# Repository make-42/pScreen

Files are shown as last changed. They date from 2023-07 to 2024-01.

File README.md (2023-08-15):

# pScreen
A small screen for displaying computer information.

## Demo video
Demo video (https://youtu.be/9QAvDlJI2AM "Demo video")

## BOM
- Raspberry Pi Pico (5.00€)
- SSD1322 (256x64) (19.08€)
- PLA for the case (0.20€)
- Various M2 screws and nuts length (choose those that fit best for your build format) (0.40€)
- Wires (0.40€)

Total: 25.08€

## Building
### 3D Printed Parts
Print all files starting with `SSD1322_` in `CAD/STLs/`.

Rotate the pieces in your slicer accordingly and print with standard settings and no supports.

(note: These files are generated from the OpenSCAD files in `CAD/OpenSCAD/`. You can modify and create new presets in the `.json` files in that directory and generate the corresponding files using OpenSCAD. The variables are made to be copied between the files. This enables quickly adding support for new screens.).

### Wiring
Wire all the parts up according to this diagram (found in `CAD/Fritzing/`).
SSD 1322 wiring

### Software
#### Firmware
Building the firmware for the Raspberry Pi Pico is as easy as installing the dependencies (`cmake` and `gcc`), cd-ing into `Software/Firmware/` and running:
```sh
git submodule update --init --recursive
sh build.sh
```
The built `.uf2` firmware files are located in `Software/Firmware/build/`.

You just need to boot your Raspberry Pi Pico into BOOTSEL mode and drag and drop them into the mounted drive to upload the firmware.

#### Client
Building the client is as simple as installing `golang`, cd-ing into `Software/Companion App/` and running:
```sh
go mod tidy
go build
```

You can then run the client with:
```sh
./pscreen
```

You can then select the connected device by pressing `b` and start broadcasting to it with `s`.

Adding and removing modules is pretty self explanatory (use `a` and `r`).

Some parameters for the client such as module tweaks, client language, resolution, speed and timeouts can be changed in `Software/Companion App/config/config.go`.

Changing these parameters requires recompiling the software.

## Afterword
I have tried making the whole project as modular and tweakable as possible. You can add new modules and new support for new screens pretty easily. If you do, don't forget to create a pull request.

If you have any questions, you can open an issue. I'd be happy to help!

Most importantly, have fun!

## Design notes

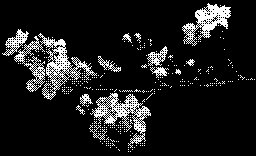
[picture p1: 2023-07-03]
Mockups/assets/bg.png

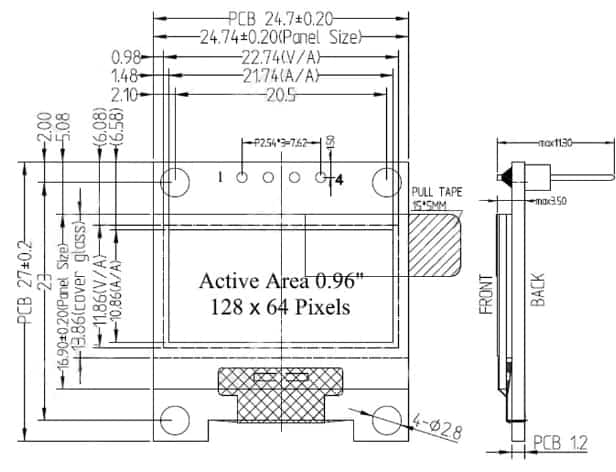
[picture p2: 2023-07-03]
CAD/Ref/oled-128x64-dimensions.jpg

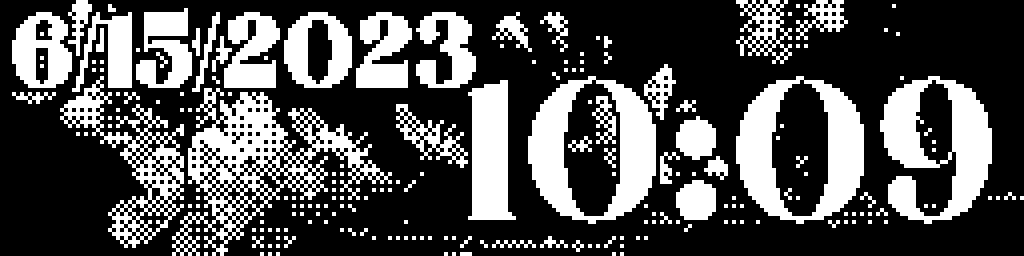
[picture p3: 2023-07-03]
Mockups/mockup-2-4x.png

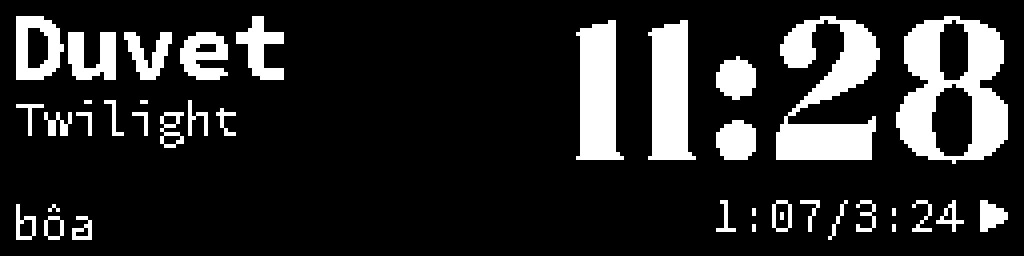
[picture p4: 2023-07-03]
Mockups/media-mockup-1-4x.png

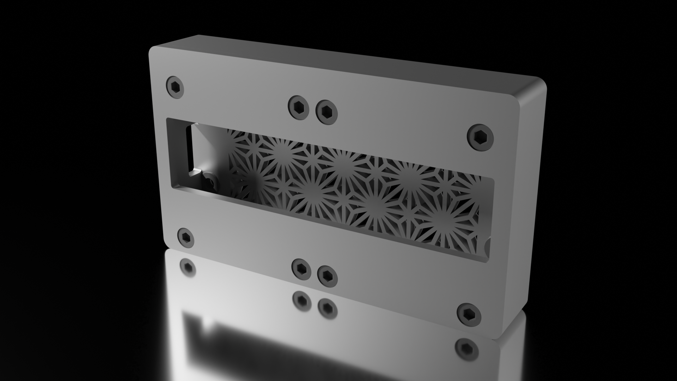
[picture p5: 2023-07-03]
CAD/Blender/cam1.png

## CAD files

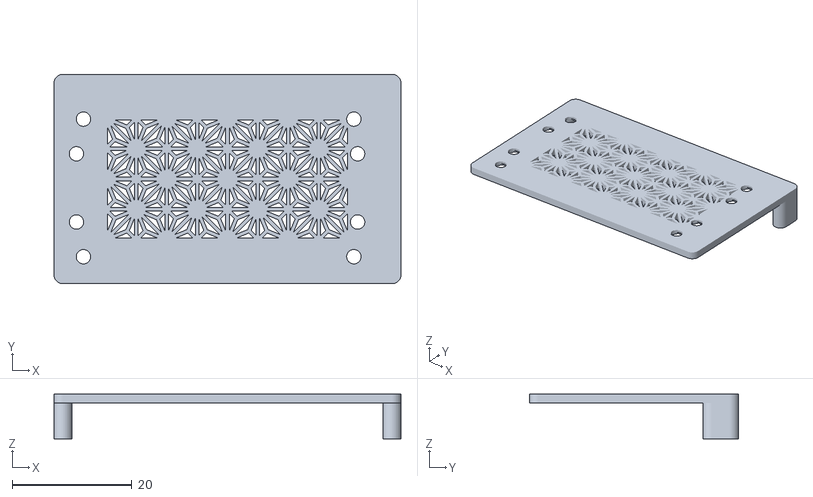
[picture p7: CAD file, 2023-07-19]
CAD/STLs/SSD1306_bottom.stl
58.0 x 35.0 x 7.50

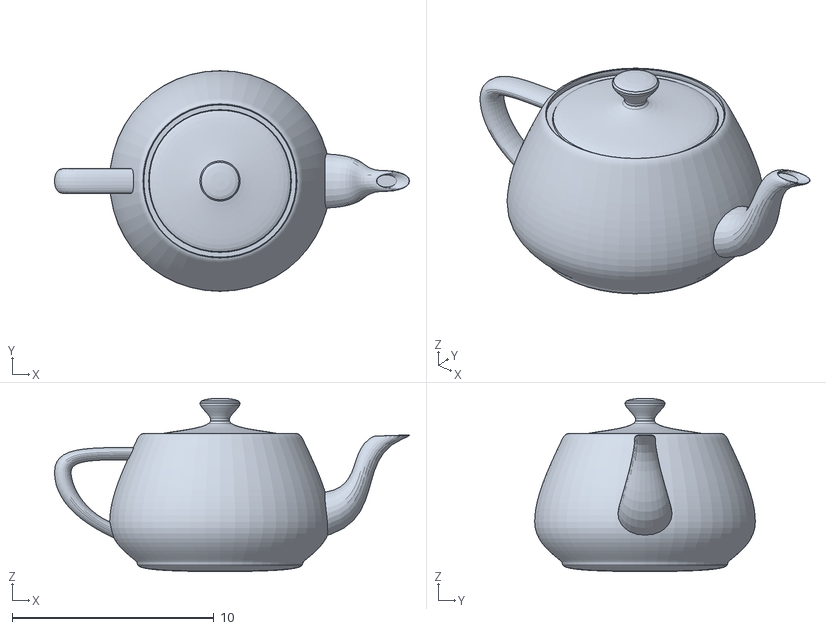
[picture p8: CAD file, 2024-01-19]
Software/Companion App/bridge/renderer/assets/3dmodels/teapot.stl
17.6 x 10.9 x 8.57

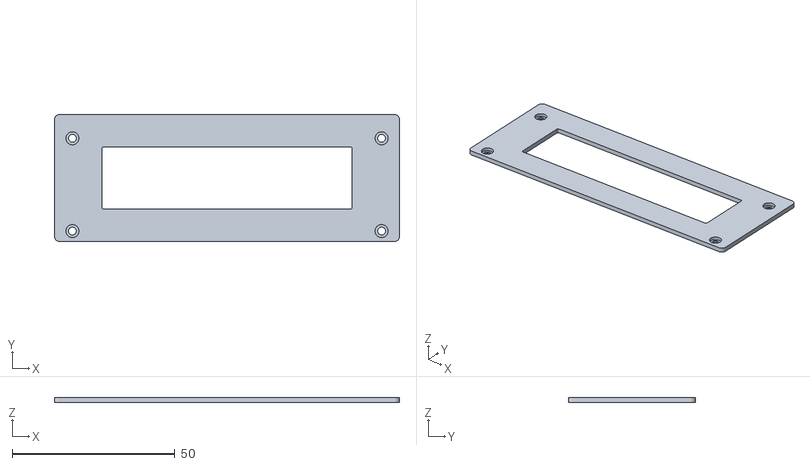
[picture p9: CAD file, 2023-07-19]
CAD/STLs/SSD1322_top.stl
106.0 x 39.0 x 1.50

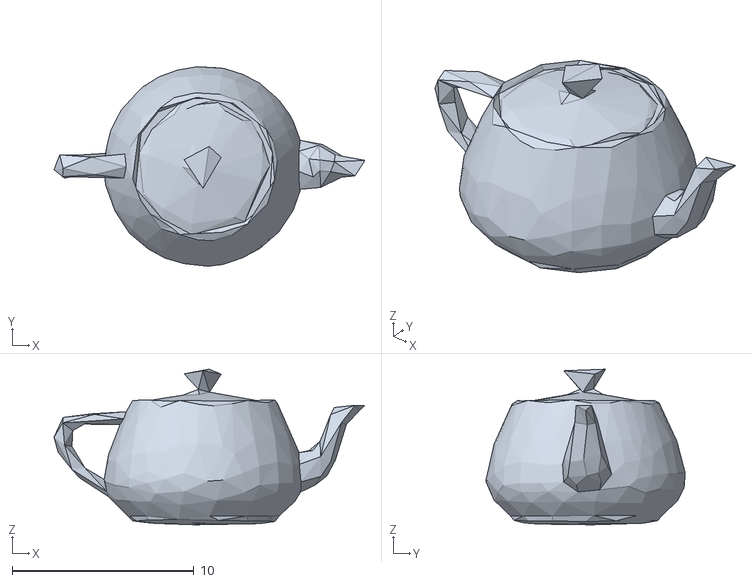
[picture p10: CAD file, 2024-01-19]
Software/Companion App/bridge/renderer/assets/3dmodels/teapot decim.stl
17.1 x 11.0 x 8.56

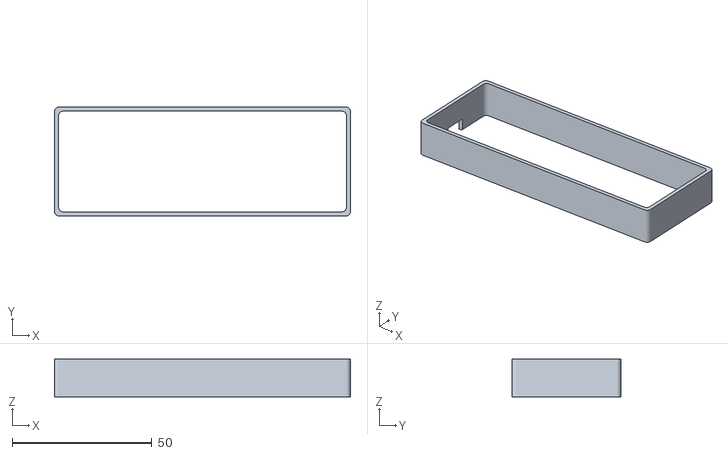
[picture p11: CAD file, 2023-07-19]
CAD/STLs/SSD1322_side.stl
106.0 x 39.0 x 13.5

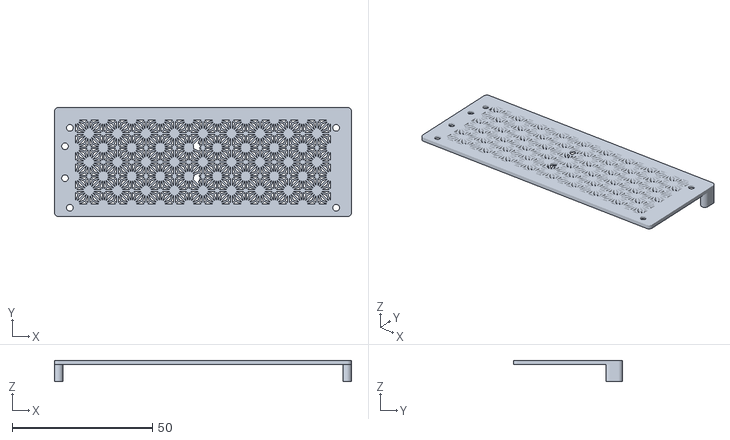
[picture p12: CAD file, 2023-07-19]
CAD/STLs/SSD1322_bottom.stl
106.0 x 39.0 x 7.50

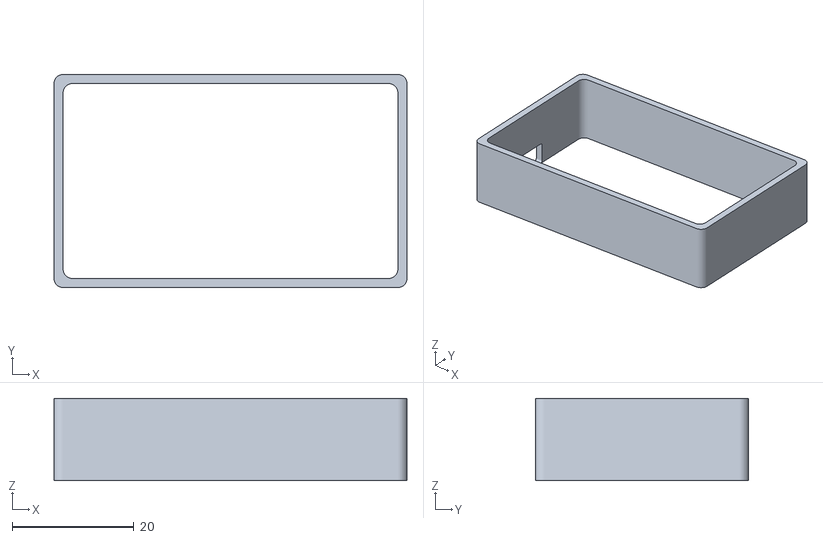
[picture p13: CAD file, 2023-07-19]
CAD/STLs/SSD1306_side.stl
58.0 x 35.0 x 13.5

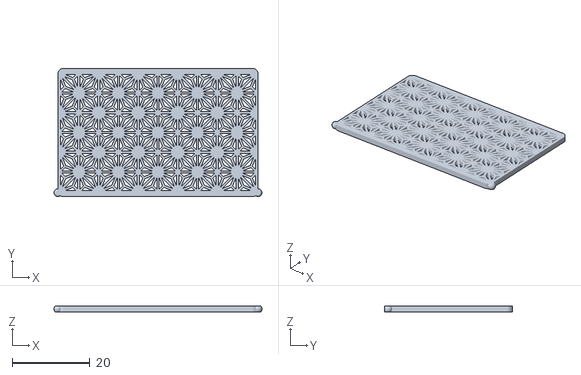
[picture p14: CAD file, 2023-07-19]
CAD/STLs/SSD1306_stand_panel.stl
53.5 x 33.0 x 1.50

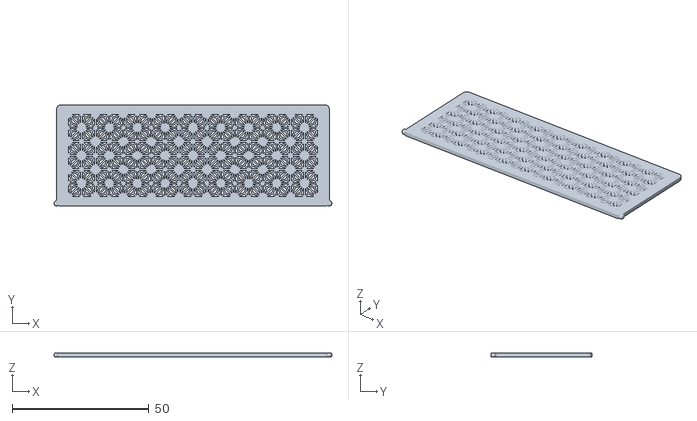
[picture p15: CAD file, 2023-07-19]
CAD/STLs/SSD1322_stand_panel.stl
101.5 x 37.0 x 1.50

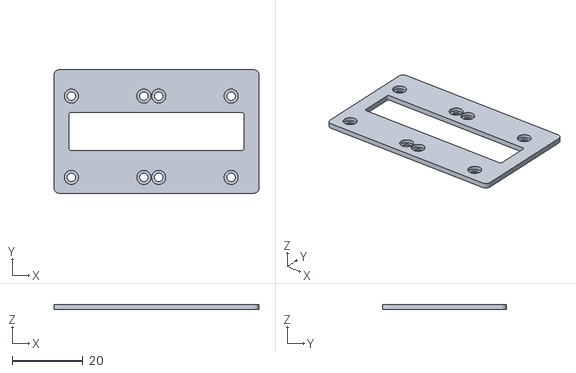
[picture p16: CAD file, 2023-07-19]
CAD/STLs/SSD1306_top.stl
58.0 x 35.0 x 1.50

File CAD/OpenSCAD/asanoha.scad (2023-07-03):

patternScale = 5.0875;
patternThickness = 0.6;
patternDepth = 10;
repeatX = 4;
repeatY = 2;

module drawLine(a=0,b=0,xStart=0,xEnd=0)
{ 
    lineLength = sqrt(pow(a*(xEnd-xStart),2)+pow(xEnd-xStart,2))+patternThickness;
    translate([xStart,a*xStart+b,0])
    rotate([0,0,atan(a)]) translate ([-patternThickness/2,-patternThickness/2,-patternDepth/2]) cube([lineLength,patternThickness,patternDepth]);  
}

module drawYLine(xOrig=0,yOrig=0,length=0)
{ 
    lineLength = length+patternThickness;
    translate([xOrig,yOrig,0])
    rotate([0,0,90]) translate ([-patternThickness/2,-patternThickness/2,-patternDepth/2]) cube([lineLength,patternThickness,patternDepth]);  
}


module asanoha(){

    interXT = patternScale/(1+tan(67.5));

    drawLine(0,0,0,patternScale);
    drawLine(-1,0,0,interXT);
    drawLine(tan(67.5),-patternScale,0,interXT);
    drawLine(tan(22.5),-patternScale*tan(22.5),interXT,patternScale);
    
    
    interXB = patternScale/(1+tan(22.5));
    
    drawLine(0,-patternScale,0,patternScale);
    drawLine(-1,0,interXB,patternScale);
    drawLine(tan(22.5),-patternScale,0,interXB);
    drawLine(tan(67.5),-patternScale*tan(67.5),interXB,patternScale);
    
    
    drawLine(1,-patternScale,0,patternScale);
    drawYLine(0,-patternScale,patternScale);
    drawYLine(patternScale,-patternScale,patternScale);
}

module movePattern(repeatXN=0,repeatYN=0){
    translate([patternScale*2*repeatXN,patternScale*2*repeatYN,0]) children();
}

module fullAsanoha(){
    asanoha();
    rotate([0,0,90]) translate([-patternScale,-patternScale,0]) asanoha();
    rotate([0,0,90]) asanoha();
    translate([patternScale,patternScale,0]) asanoha();
}

module drawAsanoha(repeatXarg=repeatX,repeatYarg=repeatY){
    translate([0,patternScale,patternDepth/2])
// Actually start drawing things
for(repeatXN = [0 : repeatXarg-1]){
    for(repeatYN = [0 : repeatYarg-1]){
        movePattern(repeatXN,repeatYN) fullAsanoha();
    }
}

}

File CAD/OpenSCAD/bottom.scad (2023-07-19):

include <BOSL2/std.scad>
include <asanoha.scad>

// Start config
// Panel Size
panel_size = [ 106, 39 ]; // mm
// Pi Board
pi_board_size = [ 51, 21 ];                                        // mm
pi_board_screw_holes_center_from_board_edge_distance = [ 2, 4.8 ]; // mm
pi_board_screw_holes_diameter = 2.1;                               // mm
pi_board_offset = [ 1.75, -1.0 ];
pi_board_usb_size = [ 8.5, 4.5 ];
pi_board_usb_rounding_radius = 0.5; // mm
// pi_board_inset_depth = 0.2; //mm (keep at zero for final)

// Screen
screen_pcb_size = [ 100.5, 33.5, 13.3 ];                                // mm (+- 0.2) 13.3mm are pin headers.
screen_pcb_screw_holes_center_from_board_edge_distance = [ 2.25, 2.5 ]; // mm
screen_pcb_screw_holes_diameter = 2.8;                                  // mm
screen_pcb_screw_holes_spacing = [ 95, 28.5 ];                          // mm
active_screen_area = [ 76.78, 19.18 ];                                  // mm (old: 13.86)
active_screen_area_offset_from_corner = [ 11.36, 5.1 ];                 // mm
screen_rounding_radius = 0.5;                                           // mm
screen_count = 1;

// Screws
m2_screw_head_depth = 1;      // mm it's 2mm normally
m2_screw_head_diameter = 4.0; // mm (adding .6mm for tolerances)
m2_screw_nut_depth = 1;       // mm it's 1.6mm normally
m2_screw_nut_diameter = 5.0;  // mm (adding .6mm for tolerances)
m2_screw_diameter = 2.4;      // mm

// Asanoha
back_asanoha_pattern_repeat = [ 9, 3 ]; // mm
asanoha_area_rounding_radius = 3;       // mm

// Stand
stand_size = [ 3, 6, 6 ];
stand_rounding_radius = 1.5;                // mm
stand_hinge_ball_diameter = 2;              // mm
stand_hinge_ball_offset = 0;                // mm
stand_panel_tolerance = 0.25;               // mm
stand_panel_thickness = 1.5;                // mm
stand_panel_rounding_radius = 1.5;          // mm
stand_asanoha_pattern_unit_length = 10.175; // mm
stand_asanoha_repeat = [ 9, 3 ];

// Misc
walls_depth = 13.5;    // mm
walls_thickness = 1.5; // mm
panel_thickness = 1.5; // mm
rounding_radius = 1.5; // mm

resolution = 80;
// End config

asanoha_pattern_size = [
    back_asanoha_pattern_repeat.x * stand_asanoha_pattern_unit_length,
    back_asanoha_pattern_repeat.y *stand_asanoha_pattern_unit_length
];
screen_x_size = screen_count == 1 ? active_screen_area.x : screen_pcb_size.x;
module asanoha_area(asanoha_anchor = [])
{
    translate(asanoha_anchor) cuboid([ asanoha_pattern_size.x, asanoha_pattern_size.y, panel_thickness ],
                                     rounding = asanoha_area_rounding_radius,
                                     edges = [ FRONT + RIGHT, FRONT + LEFT, BACK + RIGHT, BACK + LEFT ],
                                     $fn = resolution, anchor = LEFT + BOTTOM + FRONT);
}

module panel()
{
    asanoha_anchor =
        [ panel_size.x / 2 - asanoha_pattern_size.x / 2, panel_size.y / 2 - asanoha_pattern_size.y / 2, 0 ];
    difference()
    {
        cuboid([ panel_size.x, panel_size.y, panel_thickness ], rounding = rounding_radius,
               edges = [ FRONT + RIGHT, FRONT + LEFT, BACK + RIGHT, BACK + LEFT ], $fn = resolution,
               anchor = LEFT + BOTTOM + FRONT);
        asanoha_area(asanoha_anchor);
    }
    intersection()
    {
        translate(asanoha_anchor)
            drawAsanoha(repeatXarg = back_asanoha_pattern_repeat.x, repeatYarg = back_asanoha_pattern_repeat.y);
        asanoha_area(asanoha_anchor);
    }
}

module nut_hole(thread_depth = 10, nut_depth = 1.5, nut_diameter = 2, thread_diameter = 1.5)
{
    translate([ 0, 0, thread_depth / 2 + nut_depth ])
        cylinder(h = thread_depth, r = thread_diameter / 2, center = true, $fn = resolution);
    translate([ 0, 0, nut_depth / 2 ]) cylinder(h = nut_depth, r = nut_diameter / 2, center = true, $fn = 6);
}

module screen_screw_set()
{
    translate([ 0, 0 ]) nut_hole(thread_depth = panel_thickness - m2_screw_nut_depth, nut_depth = m2_screw_nut_depth,
                                 nut_diameter = m2_screw_nut_diameter, thread_diameter = m2_screw_diameter);
    translate([ screen_pcb_screw_holes_spacing.x + screen_x_size * (screen_count - 1), 0, 0 ])
        nut_hole(thread_depth = panel_thickness - m2_screw_nut_depth, nut_depth = m2_screw_nut_depth,
                 nut_diameter = m2_screw_nut_diameter, thread_diameter = m2_screw_diameter);
    translate([ 0, screen_pcb_screw_holes_spacing.y, 0 ])
        nut_hole(thread_depth = panel_thickness - m2_screw_nut_depth, nut_depth = m2_screw_nut_depth,
                 nut_diameter = m2_screw_nut_diameter, thread_diameter = m2_screw_diameter);
    translate(
        [ screen_pcb_screw_holes_spacing.x + screen_x_size * (screen_count - 1), screen_pcb_screw_holes_spacing.y, 0 ])
        nut_hole(thread_depth = panel_thickness - m2_screw_nut_depth, nut_depth = m2_screw_nut_depth,
                 nut_diameter = m2_screw_nut_diameter, thread_diameter = m2_screw_diameter);
}

module raspberry_pi_pico_screw_set()
{
    translate([
        pi_board_screw_holes_center_from_board_edge_distance.x, pi_board_screw_holes_center_from_board_edge_distance.y
    ]) nut_hole(thread_depth = panel_thickness - m2_screw_nut_depth, nut_depth = m2_screw_nut_depth,
                nut_diameter = m2_screw_nut_diameter, thread_diameter = m2_screw_diameter);
    translate([
        pi_board_screw_holes_center_from_board_edge_distance.x,
        pi_board_size.y - pi_board_screw_holes_center_from_board_edge_distance.y
    ]) nut_hole(thread_depth = panel_thickness - m2_screw_nut_depth, nut_depth = m2_screw_nut_depth,
                nut_diameter = m2_screw_nut_diameter, thread_diameter = m2_screw_diameter);
    translate([
        pi_board_size.x - pi_board_screw_holes_center_from_board_edge_distance.x,
        pi_board_screw_holes_center_from_board_edge_distance.y
    ]) nut_hole(thread_depth = panel_thickness - m2_screw_nut_depth, nut_depth = m2_screw_nut_depth,
                nut_diameter = m2_screw_nut_diameter, thread_diameter = m2_screw_diameter);
    translate([
        pi_board_size.x - pi_board_screw_holes_center_from_board_edge_distance.x,
        pi_board_size.y - pi_board_screw_holes_center_from_board_edge_distance.y
    ]) nut_hole(thread_depth = panel_thickness - m2_screw_nut_depth, nut_depth = m2_screw_nut_depth,
                nut_diameter = m2_screw_nut_diameter, thread_diameter = m2_screw_diameter);
}

module raspberry_pi_pico()
{
    rpip_anchor = [ pi_board_offset.x, pi_board_offset.y + pcb_anchor_coords.y, 0 ];
    // translate(rpip_anchor) translate ([0,0,panel_thickness-pi_board_inset_depth])
    // cube([pi_board_size.x,pi_board_size.y,pi_board_inset_depth]);
    translate(rpip_anchor) raspberry_pi_pico_screw_set();
}

module screens()
{
    screw_dist = screen_pcb_screw_holes_center_from_board_edge_distance.y + screen_pcb_screw_holes_spacing.y -
                 active_screen_area_offset_from_corner.y - active_screen_area.y;
    screw_anchor_coords = [
        pcb_anchor_coords.x + screen_pcb_screw_holes_center_from_board_edge_distance.x,
        pcb_anchor_coords.y - screw_dist, 0
    ];
    translate(screw_anchor_coords) screen_screw_set();
}

module stand_leg(invert = false)
{
    right_chirality = invert ? LEFT : RIGHT;
    left_chirality = invert ? RIGHT : LEFT;
    part_a_edges = [ FRONT + left_chirality, BACK + left_chirality ];
    part_b_edges = [ FRONT + right_chirality, BACK + right_chirality ];
    part_a_x = invert ? rounding_radius : 0;
    part_b_x = invert ? 0 : rounding_radius;
    hinge_ball_x = invert ? -stand_hinge_ball_offset : stand_size.x + stand_hinge_ball_offset;
    translate([ 0, panel_size.y - stand_size.y, 0 ]) difference()
    {
        union()
        {
            translate([ part_a_x, 0, -stand_size.z ])
                cuboid([ rounding_radius, stand_size.y, stand_size.z ], rounding = rounding_radius,
                       edges = part_a_edges, $fn = resolution, anchor = LEFT + BOTTOM + FRONT);
            translate([ part_b_x, 0, -stand_size.z ])
                cuboid([ stand_size.x - rounding_radius, stand_size.y, stand_size.z ], rounding = stand_rounding_radius,
                       edges = part_b_edges, $fn = resolution, anchor = LEFT + BOTTOM + FRONT);
        }

        translate([ hinge_ball_x, stand_size.y / 2, -stand_size.z / 2 ])
            sphere(d = stand_hinge_ball_diameter, $fn = resolution);
    }
}

module stand()
{
    stand_leg(invert = false);
    translate([ panel_size.x - stand_size.x, 0, 0 ]) stand_leg(invert = true);
}

screen_anchor_coords =
    [ panel_size.x / 2 - screen_x_size / 2 * screen_count, panel_size.y / 2 - active_screen_area.y / 2, 0 ];

pcb_anchor_coords = [ screen_anchor_coords.x - active_screen_area_offset_from_corner.x, screen_anchor_coords.y, 0 ];

union()
{
    difference()
    {
        panel();
        screens();
        raspberry_pi_pico();
    }
    stand();
}

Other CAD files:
CAD/OpenSCAD/side.scad
CAD/OpenSCAD/stand_panel.scad
CAD/Blender/SSD1322.blend
CAD/OpenSCAD/top.scad

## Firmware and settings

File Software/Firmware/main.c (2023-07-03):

/**
 * Copyright (c) 2020 Raspberry Pi (Trading) Ltd.
 *
 * SPDX-License-Identifier: BSD-3-Clause
 */

#include "pico-ssd1306/ssd1306.h"
#include "pico/stdlib.h"

#include <stdio.h>

#define BLOCKSIZE 2048
#define CANVAS_WIDTH 256
#define CANVAS_HEIGHT 64

void setup_gpios(void);

void setup_gpios(void) {
  i2c_init(i2c1, 400000);
  gpio_set_function(6, GPIO_FUNC_I2C);
  gpio_set_function(7, GPIO_FUNC_I2C);
  gpio_pull_up(6);
  gpio_pull_up(7);

  i2c_init(i2c0, 400000);
  gpio_set_function(12, GPIO_FUNC_I2C);
  gpio_set_function(13, GPIO_FUNC_I2C);
  gpio_pull_up(12);
  gpio_pull_up(13);
}

int main() {
  stdio_init_all();
  printf("configuring pins...\n");
  setup_gpios();
  int i;
  int x;
  int y;
  int z;
  char frame_buffer[BLOCKSIZE];
  ssd1306_t disp_a;
  ssd1306_t disp_b;
  disp_a.external_vcc = false;
  disp_b.external_vcc = false;
  ssd1306_init(&disp_a, 128, 64, 0x3C, i2c1);
  ssd1306_clear(&disp_a);
  ssd1306_init(&disp_b, 128, 64, 0x3C, i2c0);
  ssd1306_clear(&disp_b);
  ssd1306_draw_string(&disp_a, 0, 0, 1, "Waiting for");
  ssd1306_draw_string(&disp_b, 0, 0, 1, "companion app...");
  ssd1306_show(&disp_a);
  ssd1306_show(&disp_b);
  //  Main loop
  for (;;) {
    // Receive screen update
    for (i = 0; i < BLOCKSIZE; ++i) {
      frame_buffer[i] = getchar();
    }
    // Screen draw logic
    ssd1306_clear(&disp_a);
    ssd1306_clear(&disp_b);
    for (x = 0; x < CANVAS_WIDTH; x++) {
      for (y = 0; y < CANVAS_HEIGHT / 8; y++) {
        for (z = 0; z < 8; z++) {
          if ((frame_buffer[x * CANVAS_HEIGHT / 8 + y] >> (7 - z)) & 0x01) {
            if (x > 127) {
              ssd1306_draw_pixel(&disp_b, x - 128, y * 8 + z);
            } else {
              ssd1306_draw_pixel(&disp_a, x, y * 8 + z);
            }
          }
        }
      }
    }
    ssd1306_show(&disp_a);
    ssd1306_show(&disp_b);

    //  Send unblock command
    printf("O");
  }
}

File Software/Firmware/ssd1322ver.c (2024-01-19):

#include "comms/comms.h"
#include "hardware/gpio.h"
#include "hardware/spi.h"
#include "pico/stdlib.h"
#include "u8g2/csrc/u8g2.h"
#include <stdio.h>
#include <stdlib.h>
#include <string.h>
#include <u8g2.h>

#define CANVAS_WIDTH 256
#define CANVAS_HEIGHT 64

u8g2_t u8g2;

// Display settings
#define SPI_PORT spi0
#define PIN_CS 21
#define PIN_SCK 18
#define PIN_MOSI 19
#define SPI_SPEED 4096 * 7500
#define PIN_DC 15
#define PIN_RST 14

uint8_t u8x8_byte_pico_hw_spi(u8x8_t *u8x8, uint8_t msg, uint8_t arg_int,
                              void *arg_ptr) {
  uint8_t *data;
  switch (msg) {
  case U8X8_MSG_BYTE_SEND:
    data = (uint8_t *)arg_ptr;
    spi_write_blocking(SPI_PORT, data, arg_int);
    break;
  case U8X8_MSG_BYTE_INIT:
    u8x8_gpio_SetCS(u8x8, u8x8->display_info->chip_disable_level);
    break;
  case U8X8_MSG_BYTE_SET_DC:
    u8x8_gpio_SetDC(u8x8, arg_int);
    break;
  case U8X8_MSG_BYTE_START_TRANSFER:
    u8x8_gpio_SetCS(u8x8, u8x8->display_info->chip_enable_level);
    u8x8->gpio_and_delay_cb(u8x8, U8X8_MSG_DELAY_NANO,
                            u8x8->display_info->post_chip_enable_wait_ns, NULL);
    break;
  case U8X8_MSG_BYTE_END_TRANSFER:
    u8x8->gpio_and_delay_cb(u8x8, U8X8_MSG_DELAY_NANO,
                            u8x8->display_info->pre_chip_disable_wait_ns, NULL);
    u8x8_gpio_SetCS(u8x8, u8x8->display_info->chip_disable_level);
    break;
  default:
    return 0;
  }
  return 1;
}

uint8_t u8x8_gpio_and_delay_pico(u8x8_t *u8x8, uint8_t msg, uint8_t arg_int,
                                 void *arg_ptr) {
  switch (msg) {
  case U8X8_MSG_GPIO_AND_DELAY_INIT:
    spi_init(SPI_PORT, SPI_SPEED);
    gpio_set_function(PIN_CS, GPIO_FUNC_SIO);
    gpio_set_function(PIN_SCK, GPIO_FUNC_SPI);
    gpio_set_function(PIN_MOSI, GPIO_FUNC_SPI);
    gpio_init(PIN_RST);
    gpio_init(PIN_DC);
    gpio_init(PIN_CS);
    gpio_set_dir(PIN_RST, GPIO_OUT);
    gpio_set_dir(PIN_DC, GPIO_OUT);
    gpio_set_dir(PIN_CS, GPIO_OUT);
    gpio_put(PIN_RST, 1);
    gpio_put(PIN_CS, 1);
    gpio_put(PIN_DC, 0);
    break;
  case U8X8_MSG_DELAY_NANO: // delay arg_int * 1 nano second
    sleep_us(arg_int); // 1000 times slower, though generally fine in practice
                       // given rp2040 has no `sleep_ns()`
    break;
  case U8X8_MSG_DELAY_100NANO: // delay arg_int * 100 nano seconds
    sleep_us(arg_int);
    break;
  case U8X8_MSG_DELAY_10MICRO: // delay arg_int * 10 micro seconds
    sleep_us(arg_int * 10);
    break;
  case U8X8_MSG_DELAY_MILLI: // delay arg_int * 1 milli second
    sleep_ms(arg_int);
    break;
  case U8X8_MSG_GPIO_CS: // CS (chip select) pin: Output level in arg_int
    gpio_put(PIN_CS, arg_int);
    break;
  case U8X8_MSG_GPIO_DC: // DC (data/cmd, A0, register select) pin: Output level
    gpio_put(PIN_DC, arg_int);
    break;
  case U8X8_MSG_GPIO_RESET:     // Reset pin: Output level in arg_int
    gpio_put(PIN_RST, arg_int); // printf("U8X8_MSG_GPIO_RESET %d\n", arg_int);
    break;
  default:
    u8x8_SetGPIOResult(u8x8, 1); // default return value
    break;
  }
  return 1;
}

void display_init() {
  u8g2_Setup_ssd1322_nhd_256x64_f(
      &u8g2, U8G2_R2, u8x8_byte_pico_hw_spi,
      u8x8_gpio_and_delay_pico); // init u8g2 structure
  u8g2_InitDisplay(&u8g2);     // send init sequence to the display, display is
                               // in sleep mode after this,
  u8g2_SetPowerSave(&u8g2, 0); // wake up display
}

void waiting_for_companion_app_message() {
  u8g2_ClearBuffer(&u8g2);
  u8g2_SetDrawColor(&u8g2, 1);
  u8g2_SetFont(&u8g2, u8g2_font_timB10_tf);
  u8g2_DrawStr(&u8g2, 3, 20, "Waiting for companion app...");
  u8g2_UpdateDisplay(&u8g2);
}

int main() {
  stdio_init_all();
  display_init();
  waiting_for_companion_app_message();
  int x;
  int y;
  int z;
  char *frame_buffer_address = malloc(FRAMEBUFFER_SIZE);
  //  Main loop
  for (;;) {
    // Receive screen update
    get_frame(frame_buffer_address);

    // Screen draw logic
    u8g2_ClearBuffer(&u8g2);

    for (x = 0; x < CANVAS_WIDTH; x++) {
      for (y = 0; y < CANVAS_HEIGHT / 8; y++) {
        for (z = 0; z < 8; z++) {
          if ((frame_buffer_address[x * CANVAS_HEIGHT / 8 + y] >> (7 - z)) &
              0x01) {
            u8g2_DrawPixel(&u8g2, x, y * 8 + z);
          }
        }
      }
    }
    u8g2_UpdateDisplay(&u8g2);
    //  Send unblock command
    signal_ready_to_receive_next_frame();
  }
  free(frame_buffer_address);
}

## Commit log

2023-07-03 Everything works!
    [Wiring.fzz]
2023-07-06 Lots of changes
    [Wiring.fzz, asanoha.scad, bottom.scad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]
2023-07-19 fix: make case more compact for SSD1322
    [bottom.scad, side.scad, stand_panel.scad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]
2023-07-19 fix: make case more compact for SSD1322 -> STLs
    [SSD1306_bottom.stl, SSD1306_side.stl, SSD1306_stand_panel.stl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]
2023-07-19 fix: make case more compact for SSD1322 v2
    [SSD1306_bottom.stl, SSD1306_side.stl, SSD1306_stand_panel.stl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]
2023-07-19 fix: code firmware for SSD1322
    [ssd1322ver.c]
2023-07-20 feat: add extra features such as better logging and being able to rotate the device 180deg dynamically
2023-07-20 fix: slightly better performance
    [ssd1322ver.c]
2023-07-27 fix: change firmware waiting font
    [ssd1322ver.c]
2023-08-14 feat: consistent framerate capping, togglable layouts for circular displays(wip), togglable encoding mode for RGB displays and add assets to binary
2023-08-17 fix: achieve even higher fps
    [ssd1322ver.c]
2024-01-19 feat: teapot module
    [teapot decim.stl, teapot.stl]
